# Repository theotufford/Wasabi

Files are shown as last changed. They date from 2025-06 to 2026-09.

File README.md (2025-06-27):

# WASABI
WASABI stands for Well Applied Server Automated Biological Interface. Wasabi is a 5 bar linkage based pipetting robot that is automated via raspberry pi and the python flask library This page contains both the information and documentation for the software package as well as the mechanical assembly of the pipetting robot. The pipetting robot in this build is a slightly modified version of the [Phil pipetting robot](https://www.biorxiv.org/content/10.1101/2021.07.04.448641v1.full). Though the rpi and stepper breakout boards can be used with any machine and the wasabi machine config can be modified for any 5-bar based pipetting robot.  
## [Bill of Materials (BOM)](https://docs.google.com/spreadsheets/d/16TOlXRDoKtlOAvTiCGKz8jH9Rkvl1hXIs9z1LAUZMCc/edit?usp=sharing)

(currently working actively with this BOM but if you decide to build this project you should make your own copy and make sure to clear all of the material statuses and reset them to red so you can track)

## software outline
The core of Wasabi has three main goals:
1. intuitively program and store experiments through a visual interface 
2. run experiments and directly control the robot 

### diagram
[insert diagram here]

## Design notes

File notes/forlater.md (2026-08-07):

need to fully validate install and run script
need to configure run on network connection
make reagent db system
- figure out what factors need to be calibrated per pump and per reagent
- probably should make a configuration window
- add smooth dispense with simul z
- add reagent library input

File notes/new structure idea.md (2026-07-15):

new structure for the custom forms / methods system: python wrappers that export their structure to the interface.
works the same as registering a flask endpoint.

needs to have a name
a well select type (these are premade and chosen by name)
then the rest of the args become fields in the instruction form

I really really need to have a little lcd and some control buttons and a dial probably

needs to be made async, probably with fastapi

I need to have a busy state for the coms

need to actually implement CRC32

also add a datatype header byte

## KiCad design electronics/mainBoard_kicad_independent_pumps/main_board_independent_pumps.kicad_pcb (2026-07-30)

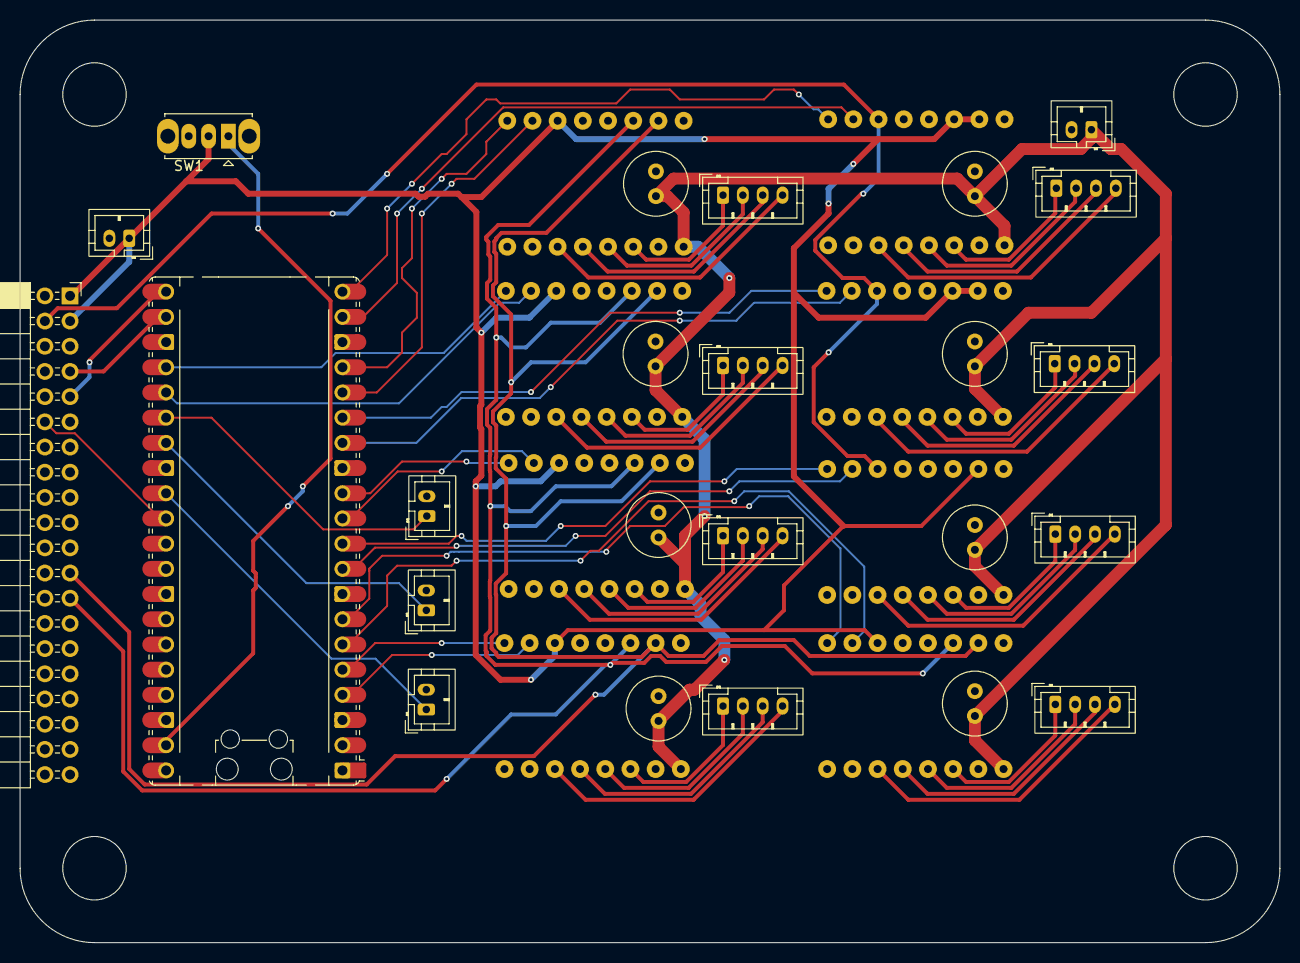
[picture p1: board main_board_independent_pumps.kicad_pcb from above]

Board: 2 copper layers, 127.0 x 93.0 mm, 32 parts (0 on the bottom side), 61 nets.

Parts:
3b+header1: PinSocket_2x20_P2.54mm_Horizontal
A1: RaspberryPi_Pico; RaspberryPi_Pico_Common_Unspecified
A_mot1: mp6500
B_mot1: mp6500
C1, C2, C3, C4, C5, C6, C7, C8: C_Small_US; C_Radial_D6.3mm_H11.0mm_P2.50mm
J1: A_lim; JST_PH_B2B-PH-K_1x02_P2.00mm_Vertical
J2: B_lim; JST_PH_B2B-PH-K_1x02_P2.00mm_Vertical
J3: Z_lim; JST_PH_B2B-PH-K_1x02_P2.00mm_Vertical
J4, J5, J6, J7, J8, J9, J12, J13: Conn_01x04_Socket; JST_PH_B4B-PH-K_1x04_P2.00mm_Vertical
J10: 5v; JST_PH_B2B-PH-K_1x02_P2.00mm_Vertical
J11: 24v; JST_PH_B2B-PH-K_1x02_P2.00mm_Vertical
SW1: SW_DPDT_x2; SW_Slide_SPDT_Straight_CK_OS102011MS2Q
pump1, pump2, pump3, pump4, pump5: mp6500
z_mot1: mp6500

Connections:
+5V: 3b+header1.1 (5V), 3b+header1.3 (5V), A_mot1.2 (MS1), A_mot1.3 (MS2), B_mot1.2 (MS1), B_mot1.3 (MS2), J10.1, SW1.2 (B), pump1.6 (VLOG), pump2.6 (VLOG), pump3.6 (VLOG), pump4.6 (VLOG), pump5.6 (VLOG), z_mot1.2 (MS1)
+24V: A_mot1.9 (VMOT), B_mot1.9 (VMOT), C1.2, C2.2, C3.2, C4.2, C5.2, C6.2, C7.2, C8.2, J11.1, pump1.9 (VMOT), pump2.9 (VMOT), pump3.9 (VMOT), pump4.9 (VMOT), pump5.9 (VMOT), z_mot1.9 (VMOT)
/A_dir: A1.20 (GPIO15), A_mot1.8 (DIR)
/A_step: A1.19 (GPIO14), A_mot1.7 (STEP)
/B_dir: A1.15 (GPIO11), B_mot1.8 (DIR)
/B_step: A1.14 (GPIO10), B_mot1.7 (STEP)
/P_ms1: 3b+header1.23 (GPIO8), pump1.2 (MS1), pump2.2 (MS1), pump3.2 (MS1), pump4.2 (MS1), pump5.2 (MS1)
/P_ms2: 3b+header1.25 (GPIO7), pump1.3 (MS2), pump2.3 (MS2), pump3.3 (MS2), pump4.3 (MS2), pump5.3 (MS2)
/Pico_reset: 3b+header1.12 (GPIO17), A1.30 (RUN)
/enable: 3b+header1.4 (GPIO2), A_mot1.6 (VLOG), B_mot1.6 (VLOG), z_mot1.6 (VLOG)
/p1_dir: A1.7 (GPIO5), pump1.8 (DIR)
/p1_step: A1.6 (GPIO4), pump1.7 (STEP)
/p2_dir: A1.17 (GPIO13), pump2.8 (DIR)
/p2_step: A1.16 (GPIO12), pump2.7 (STEP)
/p3_dir: A1.24 (GPIO18), pump3.8 (DIR)
/p3_step: A1.25 (GPIO19), pump3.7 (STEP)
/p4_dir: A1.5 (GPIO3), pump4.8 (DIR)
/p4_step: A1.4 (GPIO2), pump4.7 (STEP)
/p5_dir: A1.12 (GPIO9), pump5.8 (DIR)
/p5_step: A1.11 (GPIO8), pump5.7 (STEP)
/uart_RX: 3b+header1.9 (GPIO15), A1.21 (GPIO16)
/uart_TX: 3b+header1.7 (GPIO14), A1.22 (GPIO17)
/z_dir: A1.10 (GPIO7), z_mot1.8 (DIR)
/z_step: A1.9 (GPIO6), z_mot1.7 (STEP)
GND: 3b+header1.5 (GND), 3b+header1.10 (GND), 3b+header1.13 (GND), 3b+header1.19 (GND), 3b+header1.26 (GND), 3b+header1.33 (GND), 3b+header1.40 (GND), A1.3 (GND), A1.8 (GND), A1.13 (GND), A1.18 (GND), A1.23 (GND), A1.28 (GND), A1.33 (AGND), A1.38 (GND), A_mot1.10 (GND), A_mot1.16 (LGND), B_mot1.10 (GND), B_mot1.16 (LGND), C1.1, C2.1, C3.1, C4.1, C5.1, C6.1, C7.1, C8.1, J1.2, J2.2, J3.2, J10.2, J11.2, pump1.10 (GND), pump1.16 (LGND), pump2.10 (GND), pump2.16 (LGND), pump3.10 (GND), pump3.16 (LGND), pump4.10 (GND), pump4.16 (LGND), pump5.10 (GND), pump5.16 (LGND), z_mot1.10 (GND), z_mot1.16 (LGND)
unnamed: A1.26 (GPIO20), J3.1
unnamed: A1.27 (GPIO21), J2.1
unnamed: A1.29 (GPIO22), J1.1
unnamed: A1.39 (VSYS), SW1.1 (A)
unnamed: A_mot1.13 (A1), J4.3
unnamed: A_mot1.14 (A2), J4.4
unnamed: A_mot1.12 (B1), J4.2
unnamed: A_mot1.11 (B2), J4.1
unnamed: B_mot1.13 (A1), J5.3
unnamed: B_mot1.14 (A2), J5.4
unnamed: B_mot1.12 (B1), J5.2
unnamed: B_mot1.11 (B2), J5.1
unnamed: J6.1, z_mot1.11 (B2)
unnamed: J6.2, z_mot1.12 (B1)
unnamed: J6.3, z_mot1.13 (A1)
unnamed: J6.4, z_mot1.14 (A2)
unnamed: J7.1, pump3.11 (B2)
unnamed: J7.2, pump3.12 (B1)
unnamed: J7.3, pump3.13 (A1)
unnamed: J7.4, pump3.14 (A2)
unnamed: J8.1, pump2.11 (B2)
unnamed: J8.2, pump2.12 (B1)
unnamed: J8.3, pump2.13 (A1)
unnamed: J8.4, pump2.14 (A2)
unnamed: J9.1, pump1.11 (B2)
unnamed: J9.2, pump1.12 (B1)
unnamed: J9.3, pump1.13 (A1)
unnamed: J9.4, pump1.14 (A2)
unnamed: J12.1, pump4.11 (B2)
unnamed: J12.2, pump4.12 (B1)
unnamed: J12.3, pump4.13 (A1)
unnamed: J12.4, pump4.14 (A2)
unnamed: J13.1, pump5.11 (B2)
unnamed: J13.2, pump5.12 (B1)
unnamed: J13.3, pump5.13 (A1)
unnamed: J13.4, pump5.14 (A2)

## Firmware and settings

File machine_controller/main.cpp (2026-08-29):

#include <cmath>
#include <coms_protocol.cpp>
#include <coms_protocol.hpp>
#include <cstdlib>
#include <dma_uart.hpp>
#include <hardware/gpio.h>
#include <hardware/timer.h>
#include <hardware/uart.h>
#include <motors.cpp>
#include <motors.hpp>
#include <pico/platform/common.h>
#include <pico/time.h>
#include <pico/types.h>
#include <ratio>
#include <sys/_intsup.h>
#include <sys/unistd.h>
#include <utility>
#include <vector>

using namespace std;

int main() {
  gpio_init(LED_PIN);
  gpio_set_dir(LED_PIN, GPIO_OUT);

  blink(3);

  ComsInstance coms = ComsInstance(uart0, 115200);
  vector<Motor *> axis_motors;
  vector<Motor *> pumps;
  vector<int> pins;

  enum pin_indexes {
    MOT_ENA,
    PUMP_ENA,
    A_lim,
    B_lim,
    Z_lim,
  };

  // configuration loop that exits once everything is configured
  while (true) {
    uint messageFound = coms.get_packet(); // blocking read
    if (messageFound != 0) {
      // if read fail try again
      continue;
    }
    // listen for break signal
    if (coms.coms_rx_code == CONFIRM) {
      break;
    }

    if (coms.coms_rx_code > MACHINE_PIN_DEFINITIONS ||
        coms.coms_rx_code < NEW_PUMP) {
      continue;
    }

    if (coms.coms_rx_code == MACHINE_PIN_DEFINITIONS) {
      pins = coms.argumentVector;
      continue;
    }

    coms.send_vector(coms.coms_rx_code, coms.argumentVector);

    auto new_motor = new Motor(coms.argumentVector);
    if (coms.coms_rx_code == NEW_PUMP) {
      new_motor->is_pump = true;
      pumps.push_back(new_motor);
    } else {
      new_motor->is_pump = false;
      axis_motors.push_back(new_motor);
    }
    coms.send_code(CONFIRM);
  }

  // setup the machine pins
  for (int pin_id : pins) {
    gpio_init(pin_id);
  }

  gpio_set_dir(pins[A_lim], GPIO_IN);
  gpio_set_dir(pins[B_lim], GPIO_IN);
  gpio_set_dir(pins[Z_lim], GPIO_IN);
  gpio_set_dir(pins[MOT_ENA], GPIO_OUT);
  gpio_set_dir(pins[PUMP_ENA], GPIO_OUT);

  gpio_put(pins[MOT_ENA], 1);
  gpio_put(pins[PUMP_ENA], 1);

  gpio_pull_up(pins[A_lim]);
  gpio_pull_up(pins[B_lim]);
  gpio_pull_up(pins[Z_lim]);

  blink(3); // settings initialized blink

  coms.send_code(CONFIRM);

  // main control loop
  while (true) {
    uint messageFound = coms.get_packet(); // blocking header read
    if (messageFound != 0) {
      continue;
    }
    // state machine operated by coms rx code
    switch (coms.coms_rx_code) {
    case RE_REQUEST: {
      break;
    }
    case BUZZ: {
      int pump_id = coms.argumentVector[0];
      Motor &pump = *pumps[pump_id];
      pump.buzz();
      break;
    }
    case ENABLE_MOTORS: {
      gpio_put(pins[MOT_ENA], 1);
      break;
    }
    case DISABLE_MOTORS: {
      gpio_put(pins[MOT_ENA], 0);
      break;
    }
    case ENABLE_PUMPS: {
      gpio_put(pins[PUMP_ENA], 1);
      break;
    }
    case DISABLE_PUMPS: {
      gpio_put(pins[PUMP_ENA], 0);
      break;
    }
    case MOVE: {
      // prepare moves
      bool moved[3] = {false, false, false};

      for (int axis_ind = 0; axis_ind < 3; axis_ind++) {
        Motor &axis = *axis_motors[axis_ind];
        axis.live_abs_pos = 0;
        axis.move_delta = coms.argumentVector[axis_ind] - axis.current_position;
        if (axis.move_delta == 0) {
          continue;
        }
        axis.move_precalc();
        axis.update_dir();
        moved[axis_ind] = true;
      }

      for (int axis_ind = 0; axis_ind < 3; axis_ind++) {
        if (!moved[axis_ind])
          continue;
        Motor &axis = *axis_motors[axis_ind];
        axis.move_init_time = get_absolute_time();
        hardware_alarm_force_irq(axis.alarm_num);
      }

      for (int axis_ind = 0; axis_ind < 3; axis_ind++) {
        if (!moved[axis_ind])
          continue;
        Motor &axis = *axis_motors[axis_ind];
        while (axis.live_abs_pos != abs(axis.move_delta)) {
          tight_loop_contents();
        }
      }
      break;
    }
    case PUMP_ACTION: {
      int pump_id = coms.argumentVector[0];
      Motor &pump = *pumps[pump_id];
      pump.vMax = coms.argumentVector[1];
      pump.ang_accel = coms.argumentVector[2];
      int step_count = coms.argumentVector[3];
      if (step_count == 0) {
        break;
      }

      bool is_aspiration = step_count < 0;

      int accel_distance_steps =
          floor((pump.vMax * pump.vMax) / (2. * pump.ang_accel) * pump.TOSTEPS);

      if (is_aspiration) {
        pump.singular_linear_move(step_count);
      } else {
        pump.singular_accel_move(-accel_distance_steps);
        step_count += accel_distance_steps;
        sleep_ms(50);
        pump.singular_accel_move(step_count);
      }
      break;
    }
    case HOME: {

      for (int axis_ind = 0; axis_ind < 3; axis_ind++) {
        Motor &axis = *axis_motors[axis_ind];
        axis.live_abs_pos = 0;
      }

      Motor &amot = *axis_motors[0];
      Motor &bmot = *axis_motors[1];
      Motor &zmot = *axis_motors[2];

      amot.live_abs_pos = 0;
      bmot.live_abs_pos = 0;
      zmot.live_abs_pos = 0;
      amot.set_dir(1);
      bmot.set_dir(-1);
      zmot.set_dir(-1);

      vector<int> initial_position = {0, 0, 0};

      // b and z motor are moving in reverse to home
      // because their limit switches are at 0
      // home z first to avoid physical collisions
      while (true) {
        bool z_triggered = !gpio_get(pins[Z_lim]);
        if (z_triggered) {
          initial_position[2] = zmot.live_abs_pos;
          zmot.current_position = 0;
          break;
        }
        zmot.step();
        sleep_us(500);
      }

      while (true) {
        bool a_triggered = !gpio_get(pins[A_lim]);
        bool b_triggered = !gpio_get(pins[B_lim]);

        if (a_triggered) {
          int homing_switch_step_pos = ceil(amot.stp_per_rev * 250. / 360.);
          initial_position[0] = homing_switch_step_pos - amot.live_abs_pos;
          amot.current_position = homing_switch_step_pos;
        } else {
          amot.step();
        }
        if (b_triggered) {
          initial_position[1] = bmot.live_abs_pos;
          bmot.current_position = 0;
        } else {
          bmot.step();
        }

        if (a_triggered && b_triggered) {
          break;
        }

        sleep_ms(3);
      }
      coms.send_vector(INITIAL_POSITION, initial_position);
      break;
    }
    }
    coms.send_code(CONFIRM);
  }
}

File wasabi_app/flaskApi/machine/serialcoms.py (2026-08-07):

#!./.venv/bin/python
import asyncio
import serial
import math
import RPi.GPIO as pio
import zlib
import time
import json
import struct
from .kinematics import Vec2d, solve_5bar_FK, solve_5bar_IK

pio.setmode(pio.BCM)


def int_vec_to_bytes(intgr_arr: list[int]) -> bytearray:
    outData = bytearray()
    for intgr in intgr_arr:
        outData += intgr.to_bytes(4, 'little', signed=True)
    return outData


TIMEOUT_S = 999

COMS_START_BYTE = b"\xf8"
EMPTY = 0
WAKE = 1
CONFIRM = 2
MESSAGE = 3
ERROR = 4
RE_REQUEST = 5
NEW_PUMP = 6
A_MOTOR = 7
B_MOTOR = 8
Z_MOTOR = 9
MACHINE_PIN_DEFINITIONS = 10
MOVE = 11
PUMP_ACTION = 12
ENABLE_PUMPS = 13
DISABLE_PUMPS = 14
ENABLE_MOTORS = 15
DISABLE_MOTORS = 16
HOME = 17
INITIAL_POSITION = 18
BUZZ = 19

COMS_INV = [
    "EMPTY",
    "WAKE",
    "CONFIRM",
    "MESSAGE",
    "ERROR",
    "RE_REQUEST",
    "NEW_PUMP",
    "A_MOTOR",
    "B_MOTOR",
    "Z_MOTOR",
    "MACHINE_PIN_DEFINITIONS",
    "MOVE",
    "PUMP_ACTION",
    "ENABLE_PUMPS",
    "DISABLE_PUMPS",
    "ENABLE_MOTORS",
    "DISABLE_MOTORS",
    "HOME",
    "INITIAL_POSITION",
    "BUZZ"
]


# abstracts the encode - decode process

class Packet:
    def __init__(self, code, datalen, data: bytearray):
        if datalen > 256:
            raise ValueError("packet data too large!")
        self.code = code
        self.datalen = datalen
        self.data = data
        self.checksum = 0

    def __repr__(self):
        return f"""
            {COMS_INV[self.code]}
            data: {self.data}
            calculated checksum: {self.calculate_checksum()}
            rx checksum:         {self.checksum}
        """
    # packet structure is strictly ordered by byte:
    # 0: start byte
    # 1: coms code
    # 2: data length
    # 3 to n + 3: data
    # n+4 to n+8: checksum

    def calculate_checksum(self) -> bytearray:
        message_bytes = self.make_header()
        message_bytes += self.data
        return zlib.crc32(message_bytes).to_bytes(4, byteorder='little')

    def make_header(self) -> bytearray:
        header = bytearray(COMS_START_BYTE)
        header += self.code.to_bytes(1)
        header += self.datalen.to_bytes(1)
        return header

    def get_full_bytes(self) -> bytearray:
        out_bytes = self.make_header()
        out_bytes += self.data
        out_bytes += zlib.crc32(out_bytes).to_bytes(4, byteorder='little')
        return out_bytes

    def get_int_argvec(self) -> list:
        intgr_iter = struct.iter_unpack("<i", self.data)
        argvec = [intgr[0] for intgr in intgr_iter]
        return argvec


def parse_header(header: bytearray) -> Packet:
    coms_code = int(header[1])
    datalen = int(header[2])
    new_packet = Packet(coms_code, datalen, b"")
    return new_packet


def make_new_packet(code, data: bytearray) -> Packet:
    return Packet(code=code, datalen=len(data), data=data)


class ComsChannel:

    def __init__(self):
        self.errcount = 0
        self.most_recent_rx: Packet
        self.most_recent_tx: Packet
        # initialize serial contact
        self.ser = serial.Serial("/dev/ttyS0", 115200, timeout=TIMEOUT_S)

        self.startup_handshake()

    def startup_handshake(self):
        while True:
            asyncio.run(self.get_packet())
            code = self.most_recent_rx.code
            if code == WAKE:
                print("wake rxd")
                self.send_code(CONFIRM)
                continue
            if code == CONFIRM:
                self.send_code(CONFIRM)
                print("coms initialized")
                break
            raise ValueError(
                f"was expecting wake or confirm during boot, got: {code}")
        self.get_confirm()

    def __del__(self):
        self.ser.close()
        pio.cleanup()

    def re_request(self):
        return
        self.ser.reset_input_buffer()
        self.send_code(RE_REQUEST)

    def get_confirm(self):
        start = time.perf_counter()
        while True:
            asyncio.run(self.get_packet())
            code = self.most_recent_rx.code
            if code == CONFIRM:
                break
            current = time.perf_counter()
            if current - start > TIMEOUT_S:
                raise TimeoutError(
                    f"waited {TIMEOUT_S} seconds without recieving a confirm")

    def send_packet(self, message: Packet) -> None:
        # self.check_and_handle_re_req()
        print(f"sending {COMS_INV[message.code]} {message.get_int_argvec()}")
        self.most_recent_tx = message
        self.ser.write(message.get_full_bytes())

    def send_data(self, code, data) -> None:
        tmp = make_new_packet(code, data)
        self.send_packet(tmp)

    def send_code(self, code) -> None:
        self.send_data(code, b"")

    def send_int_vec(self, code, intgr_arr: list[int]) -> None:
        data = int_vec_to_bytes(intgr_arr)
        pack = make_new_packet(code, data)
        self.send_packet(pack)

    # meant to recieve absolute position in step units
    def send_move_steps(self, alpha: int, beta: int, z: int):
        self.send_int_vec(MOVE, [alpha, beta, z])
        self.get_confirm()

    def send_pump_action_steps(self, motor_id, speed, accel, vol_step_count):
        self.send_int_vec(PUMP_ACTION, [ motor_id, speed, accel, vol_step_count])
        self.get_confirm()

    async def check_and_handle_CRC32(self, callback: callable):
        start = time.perf_counter()
        current = start
        while self.ser.in_waiting < 4:
            if current - start > TIMEOUT_S:
                self.ser.reset_input_buffer()
                print("\n\nNon fatal error: missing checksum. Re-requesting\n\n")
                self.re_request()
                await self.get_packet()
            current = time.perf_counter()

        given = self.ser.read(4)
        self.most_recent_rx.checksum = given
        calculated = self.most_recent_rx.calculate_checksum()
        return
        if given != calculated:
            print(f"CRC error detected!! error counter is now {
                  self.errcount}, erroring packet:\n{self.most_recent_rx}")
            self.re_request()
            callback()

    async def get_header(self, timeout):
        self.most_recent_rx = Packet(EMPTY, 0, b"")
        start = time.perf_counter()
        while True:
            if self.ser.in_waiting > 0:
                initial_byte = self.ser.read(1)
                if initial_byte == COMS_START_BYTE:
                    break
                else:
                    continue
            current = time.perf_counter()
            if current - start > timeout:
                return None
        header_data = bytearray(COMS_START_BYTE)
        header_data += self.ser.read(2)
        self.most_recent_rx = parse_header(header_data)
        return self.most_recent_rx
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

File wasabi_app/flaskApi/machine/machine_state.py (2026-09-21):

import time
import string
from typing import Literal
import copy
import asyncio
from ..db import get_db
import math
import inspect
import json
from typing import Self
import RPi.GPIO as pio
from .kinematics import solve_5bar_FK, solve_5bar_IK, MachinePosition, Vec2d, make_pos
from . import serialcoms as serlib
from .utils import alph_to_vec, vec_to_alph


class Reagent_Mix:
    def __init__(self, contents={}, is_reservoir=False):
        self.contents = contents
        self.is_reservoir = False

    def get_total_volume(self):
        if self.is_reservoir:
            return 1
        total_volume = 0
        for reagent in self.contents:
            held_volume = self.contents[reagent]
            total_volume += held_volume
        return total_volume

    def release_volume(self, target_volume):
        released_volume = Reagent_Mix()
        released_volume.contents = self.contents
        v_total = self.get_total_volume()
        for reagent in self.contents:
            volume = (self.contents[reagent] / v_total) * target_volume
            if not self.is_reservoir:
                self.contents[reagent] -= volume
            released_volume.contents[reagent] = volume

        return released_volume

    def __repr__(self):
        return f"{self.contents}"

    def gain_reagent(self, reagent, volume=0,  reservoir=False):
        if self.is_reservoir:
            return ValueError("attempting to add reagent to mix that is reservoir with indeterminate volume")
        self.empty = False
        self.is_reservoir = reservoir
        if reservoir:
            self.contents[reagent] = 1
            return
        if not self.contents.get(reagent):
            self.contents[reagent] = 0
        self.contents[reagent] += volume

    def gain_mixed_volume(self, liquid: Self):
        if self.is_reservoir:
            return ValueError("attempting to add reagent to mix that is reservoir with indeterminate volume")
        for reagent in liquid.contents:
            volume = liquid.contents[reagent]
            self.gain_reagent(reagent, volume)


class Well:
    def __init__(self, settings, relative_position: Vec2d, contents={}):
        self.relative_position = relative_position
        self.absolute_position: MachinePosition()
        self.liquid = Reagent_Mix(contents)
        self.major_diameter = settings["major_diameter"]
        self.minor_diameter = settings["minor_diameter"]
        self.depth = settings["well_depth"]

    def release_aspirate(self, volume) -> Reagent_Mix:
        return self.liquid.release_volume(volume)

    def gain_liquid(self, liquid: Reagent_Mix):
        if liquid is None:
            return
        return self.liquid.gain_mixed_volume(liquid)


class Plate:
    def __init__(self, settings: dict):
        self.settings = settings
        self.rows = settings["rows"]
        self.columns = settings["columns"]
        self.spacing = settings["spacing"]
        self.wells: list[Well] = self.make_clear_plate()

    def make_clear_plate(self):
        wells = []
        for row_y in range(0, self.rows):
            for col_x in range(0, self.columns):
                new_well = Well(self.settings, self.spacing *
                                Vec2d(col_x, row_y))
                wells.append(new_well)
        return wells

    def by_alph(self, alph):
        for well in self.wells:
            col_row_vec = well.relative_position / self.spacing
            wellid = vec_to_alph(col_row_vec)
            if alph == wellid:
                return well

    def by_relative_position(self, vec: Vec2d):
        for well in self.wells:
            dist_to_center = (vec - well.relative_position).get_length()
            if dist_to_center < self.spacing / 2:
                return well

    def reset_plate(self):
        self.by_alph = self.make_clear_plate()

    def get_well_vol_dict(self):
        out = {}
        for alph in self.by_alph():
            well = self.by_alph(alph)
            out[alph] = well.liquid.contents
        return out

    def __repr__(self):
        return f"{self.rows}x{self.columns}; {self.spacing}mm"


class Machine:
    def __init__(self, settings_path, method_library):
        self.settings_path = settings_path
        mach = self.settings()["machine"]
        self.current_position = MachinePosition()
        self.home_offset = MachinePosition()
        self.aspiration_depth_offset = 0
        self.methods: MethodLibrary = method_library
        self.methods.machine = self
        self.motors_enabled = True
        self.abs_plate_map = {}
        self.error = None
        self.position_known = False
        self.in_simulation = False
        self.impure_method_flag = False
        self.coms: serlib.ComsChannel
        self.waste_well = Well(
            self.settings()["plates"]["150ml_waste_beaker"], Vec2d(0, 0))
        self.current_well = self.waste_well
        spr = mach["motors"]["common_settings"]["kinematic_steps_per_revolution"]
        pitch = mach["machineDimensions"]["z_screw_pitch"]
        self.a_steps_per_rad = spr / (2 * math.pi)
        self.b_steps_per_rad = spr / (2 * math.pi)
        self.z_steps_per_mm = spr / pitch

        self.pump_line_contents = {}
        pumps = mach["motors"]["pumps"]
        for id in range(0, len(pumps)):
            line_contents = Reagent_Mix()
            line_contents.gain_reagent(
                f"{self.get_reagent(id)}", reservoir=True)
            self.pump_line_contents[id] = [line_contents]
        print(f"pump line: {self.pump_line_contents}")

        self.plate = Plate(self.settings()["plates"]["standard 96"])
        self.hw_init()

    def settings(self):
        with open(self.settings_path, "r") as conf:
            settings = json.load(conf)
            return settings

    def hw_init(self):
        # reboot the pico
        pi3b_pins = self.settings()["machine"]["pins"]["on_3b_server_board"]
        pico_reset_pin = pi3b_pins["pico_reset_pin"]
        stage_enable_pin = pi3b_pins["stage_enable_pin"]
        pump_ms1 = pi3b_pins["pump_ms1"]
        pump_ms2 = pi3b_pins["pump_ms2"]
        pio.setup(pico_reset_pin, pio.OUT)
        pio.setup(stage_enable_pin, pio.OUT)
        pio.setup(pump_ms1, pio.OUT)
        pio.setup(pump_ms2, pio.OUT)

        pio.output(stage_enable_pin, pio.HIGH)
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

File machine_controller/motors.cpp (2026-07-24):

#include <cmath>
#include <csignal>
#include <cstdint>
#include <cstdlib>
#include <dma_uart.hpp>
#include <exception>
#include <hardware/gpio.h>
#include <hardware/timer.h>
#include <motors.hpp>
#include <pico/time.h>
#include <vector>

using namespace std;

void Motor::move_isr(uint alarm_num) {
  Motor *mot = Motor::async_bay.at(alarm_num);
  int init_move = mot->move_callback();
}

Motor::Motor(const vector<int> &argumentVector)
    : step_pin(argumentVector[step_pin_arg]),
      dir_pin_inverted(argumentVector[invert_dir_arg]),
      dir_pin(argumentVector[dir_pin_arg]),
      stp_per_rev(argumentVector[stp_per_rev_arg]),
      vMax(argumentVector[ang_v_max_arg]),
      ang_accel(argumentVector[ang_accel_arg]), live_abs_pos(0), move_delta(0),
      current_position(0), direction(1) {
  gpio_init(dir_pin);
  gpio_init(step_pin);
  gpio_set_dir(step_pin, GPIO_OUT);
  gpio_set_dir(dir_pin, GPIO_OUT);
  gpio_put(dir_pin, dir_pin_inverted);
}

void Motor::buzz() {

  float buzz_amplitude_deg = 3.6;

  int amp_steps = (int)(buzz_amplitude_deg / (360.f / (float)stp_per_rev));

  if (amp_steps < 0) {
    amp_steps = 1;
  }
  move_delta = 1;
  for (int cycle_count = 0; cycle_count < 50; cycle_count++) {
    for (int stpcnt = 0; stpcnt < amp_steps; stpcnt++) {
      step();
      sleep_ms(5);
    }
    set_dir(-direction);
  }
}

void Motor::update_dir() {
  direction = move_delta / abs(move_delta);
  bool bin_dir = direction > 0;
  if (dir_pin_inverted) {
    bin_dir = !bin_dir;
  }
  gpio_put(dir_pin, bin_dir);
}

void Motor::set_dir(int dir) {
  direction = dir;
  bool bin_dir = direction > 0;
  if (dir_pin_inverted) {
    bin_dir = !bin_dir;
  }
  gpio_put(dir_pin, bin_dir);
}

void Motor::step() {
  // step logic
  gpio_put(step_pin, 1);
  sleep_us(1);
  gpio_put(step_pin, 0);
  current_position += direction;
  live_abs_pos++;
  // set calculate flag high
}

void Motor::move_precalc() {
  ang_targ_dist = TORADS * abs(move_delta); // gets the total distance
  float v_reached = vMax;
  // if the max v isnt reached by halfway
  // we use the highest v reached as the
  // vmax in our calculations
  bool short_hop = (ang_targ_dist / 2) < ((float)(vMax * vMax) / ang_accel);
  if (short_hop && !is_pump) {
    v_reached = sqrt(ang_targ_dist * ang_accel);
  }
  accel_stop = (v_reached * v_reached) / (2. * ang_accel);
  constv_stop = (ang_targ_dist - (v_reached * v_reached) / (2 * ang_accel));
  total_move_time = (ang_targ_dist / v_reached + v_reached / ang_accel);
  claim_isr();
  return;
}

void Motor::claim_isr() {
  alarm_num = hardware_alarm_claim_unused(false);
  if (alarm_num == -1) {
    buzz();
    buzz();
    buzz();
  }
  Motor::async_bay[alarm_num] = this;
  hardware_alarm_set_callback(alarm_num, (hardware_alarm_callback_t)move_isr);
}

int Motor::move_callback() {
  step();
  if (live_abs_pos == abs(move_delta)) {

    hardware_alarm_unclaim(alarm_num);
    return 0;
  }

  double theta = TORADS * (live_abs_pos + 1);
  double stepTiming;

  if (theta < accel_stop) {
    stepTiming = sqrt((2 * theta) / ang_accel);
  } else if (theta < constv_stop || is_pump) {
    stepTiming = (theta / vMax) + (vMax / (2. * ang_accel));
  } else {
    stepTiming =
        total_move_time - sqrt((2 * (ang_targ_dist - theta)) / ang_accel);
  }

  uint64_t next_step_time = (uint64_t)(stepTiming * 1e6f);
  hardware_alarm_set_target(alarm_num,
                            delayed_by_us(move_init_time, next_step_time));
  return 0;
}

void Motor::singular_accel_move(int step_count) {
  live_abs_pos = 0;
  move_delta = step_count;
  move_precalc();
  update_dir();
  move_init_time = get_absolute_time();
  hardware_alarm_force_irq(alarm_num);
  while (live_abs_pos != abs(move_delta)) {
    tight_loop_contents();
  }
}
void Motor::singular_linear_move(int step_count) {
  live_abs_pos = 0;
  move_delta = step_count;
  update_dir();
  uint64_t delay = (uint64_t)( 0.25 * 1e6f/(vMax * TOSTEPS));
  while (live_abs_pos != abs(move_delta)) {
    sleep_us(delay);
    step();
  }
}

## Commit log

2025-04-08 wasabi breakout board pcb
    [wasabi-B_Cu.gbl, wasabi-B_Mask.gbs, wasabi-B_Paste.gbp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]
2025-05-21 updated PCBs
    [picowasabi-B_Cu.gbr, picowasabi-B_Mask.gbr, picowasabi-B_Paste.gbr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]
2025-05-31 working motors with picols
2025-05-31 motors working!
2025-06-12 working on the motor controller
2025-06-26 updated board design
    [wasabi-B_Cu.gbr, wasabi-B_Mask.gbr, wasabi-B_Paste.gbr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]
2025-06-26 motor controller working
2025-06-26 added untracked files
    [picowasabi-B_Cu.gbr, picowasabi-B_Mask.gbr, picowasabi-B_Paste.gbr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]
2025-06-27 modified ignore file and added search and log functionality to the material selector in the programmer forms
2025-07-07 fixed some visual bugs with the plate rendering as well as some other stuff I sort of forgot, gotta get into a better habit of pushing a commit at the end of every coding session so I can track chang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
2025-08-05 trying to be better about committing daily, really just for the vain reason that I want my heatmap to be green lol
2025-08-08 sockets successfully exchange experiment object between back and frontend
2025-12-01 prototype web serial monitor functioning with counter
2026-01-05 starting redevelopment of machine controller this time in c++ and with a correctly structured library
    [dma_uart.cpp, dma_uart.hpp, fiveBar.cpp]
2026-02-15 working buzz function
    i need to stop doing the thing where i dont initialize my for loop index
    variable
    [fiveBar.cpp, main.cpp]
2026-02-15 working absolute positioning with linear velocity
2026-03-18 split up files
    no more machine class, decided that entire functionality can be left to
    static variabless in the Motor class, as it sort of has to be anyways.
2026-06-15 some updates and lots of electronics stuff
    [freerouting.dsn, mainBoard_kicad.kicad_pcb, mainBoard_kicad.kicad_sch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]
2026-06-20 coms updates
    [machine_config.json]
2026-06-20 kinematics working
2026-07-02 first working control integration
    [freerouting.dsn, machine_config.json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]
2026-07-02 main board update
2026-07-02 dev board
    [main_board_independent_pumps.kicad_pcb, main_board_independent_pumps.kicad_sch]
2026-07-02 pre-working home button
2026-07-02 working home button!
    [machine_config.json]
2026-07-08 working jog button, closing in on being able to run experiments, much progress on pumps
    [machine_config.json]
2026-07-08 working pump table updating with database
2026-07-10 first fully functional version that can run an experiment!!!!!!!!!
    [machine_config.json]
2026-07-15 full chain working, gradient method buggy still, commit before beginning work on wrapping
    [machine_config.json]
2026-07-21 pi changes
    [machine_config.json]
2026-07-21 properly using context hook!
    [machine_config.json]
2026-07-24 prelim changes
    [machine_config.json, main_board_independent_pumps.kicad_pcb, main_board_independent_pumps.kicad_sch]
2026-07-30 i forgor
    [machine_config.json]
2026-07-30 some board changes
    [main_board_independent_pumps.kicad_pcb]
2026-07-30 Squash merge board-changes into main
    [main_board_independent_pumps.kicad_pcb]
2026-07-30 pump speed per send
2026-08-07 base working wrapper method system
    [machine_config.json]
2026-08-13 basic volume output simulations
    [machine_config.json]
2026-08-25 some changes
    [machine_config.json]
2026-08-27 many interface changes, working on function purity verification and better plate viewing
    [machine_config.json]
2026-08-29 more work on plate readout
    [machine_config.json]
2026-08-29 fixed off by one in firmware
    [main.cpp]
2026-09-03 built reagent db system
    [machine_config.json]
2026-09-05 some bug fixes, working along
    [machine_config.json]
2026-09-14 various updates I forgot, going to start working on output plate
    [machine_config.json]
2026-09-21 various testing methods added, mostly working on pump reliability in the physical world
    [machine_config.json]
2026-09-24 updated install script and config constants
    [machine_config.json]
